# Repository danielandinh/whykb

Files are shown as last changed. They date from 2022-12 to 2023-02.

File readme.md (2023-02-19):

# Custom Keyboard Project

40% board w oled and knob

## Handwired Prototype
<sup><sub>not a bomb</sub></sup>

front
back

keyboard specs:
* GMK Pixel
* Gateron Milky Yellows L/F
* [3D Printed Plate](cad/plate_whole.stl)
* Durock plate mount stabs
* OLED and Knob

## PCB for sea-picro board

front
back

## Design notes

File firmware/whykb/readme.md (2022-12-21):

# handwired/whykb

front

*Handwired keyboard kinda like a 40% but with arrow cluster, supports OLED Display and Rotary Encoder*

* Keyboard Maintainer: [Daniel Dinh](https://github.com/danielandinh)
* Hardware Supported: *MUC: [rp2040](https://joshajohnson.com/sea-picro/), OLED: SSD1306*

Make example for this keyboard (after setting up your build environment):

    make handwired/whykb:default

Flashing example for this keyboard:

    make handwired/whykb:default:flash

See the [build environment setup](https://docs.qmk.fm/#/getting_started_build_tools) and the [make instructions](https://docs.qmk.fm/#/getting_started_make_guide) for more information. Brand new to QMK? Start with our [Complete Newbs Guide](https://docs.qmk.fm/#/newbs).

## Bootloader

Enter the bootloader in 3 ways:

* **Bootmagic reset**: Hold down the key at (0,0) in the matrix (usually the top left key or Escape) and plug in the keyboard
* **Physical reset button**: Briefly press the button on the back of the PCB - some may have pads you must short instead
* **Keycode in layout**: Press the key mapped to `QK_BOOT` if it is available

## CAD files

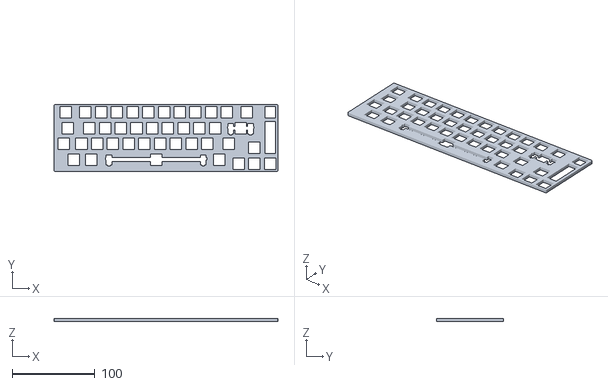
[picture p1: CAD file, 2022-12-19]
cad/plate_whole.stl
271.5 x 81.0 x 3.60

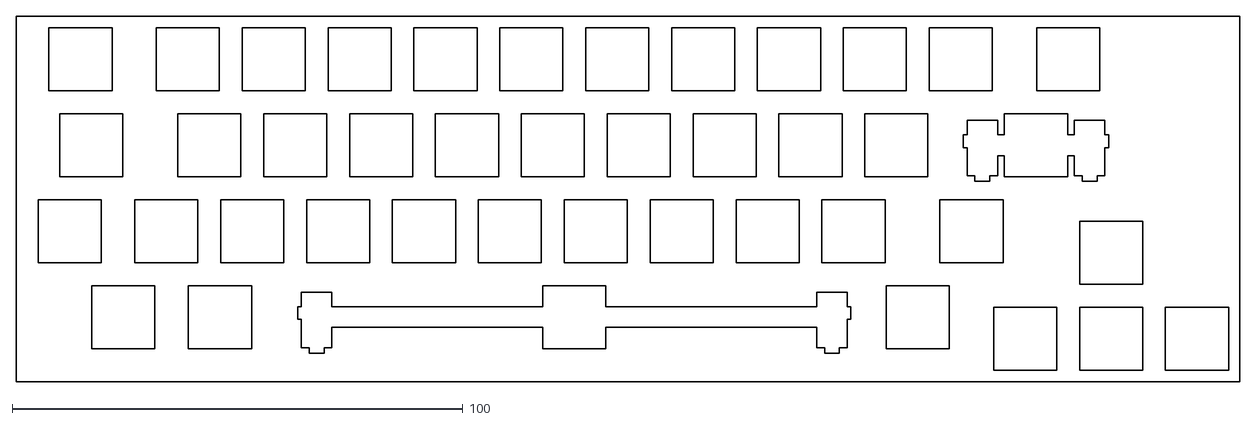
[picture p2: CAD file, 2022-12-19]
cad/whykb_plate.dxf
271.5 x 81.0

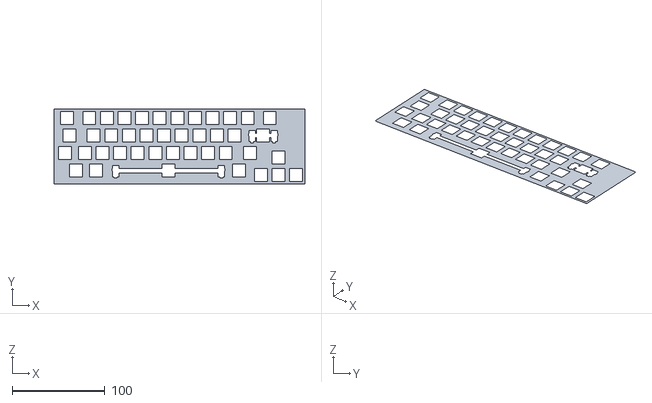
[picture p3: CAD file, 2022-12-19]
cad/plate_cad.STL
271.4 x 80.9 x 0

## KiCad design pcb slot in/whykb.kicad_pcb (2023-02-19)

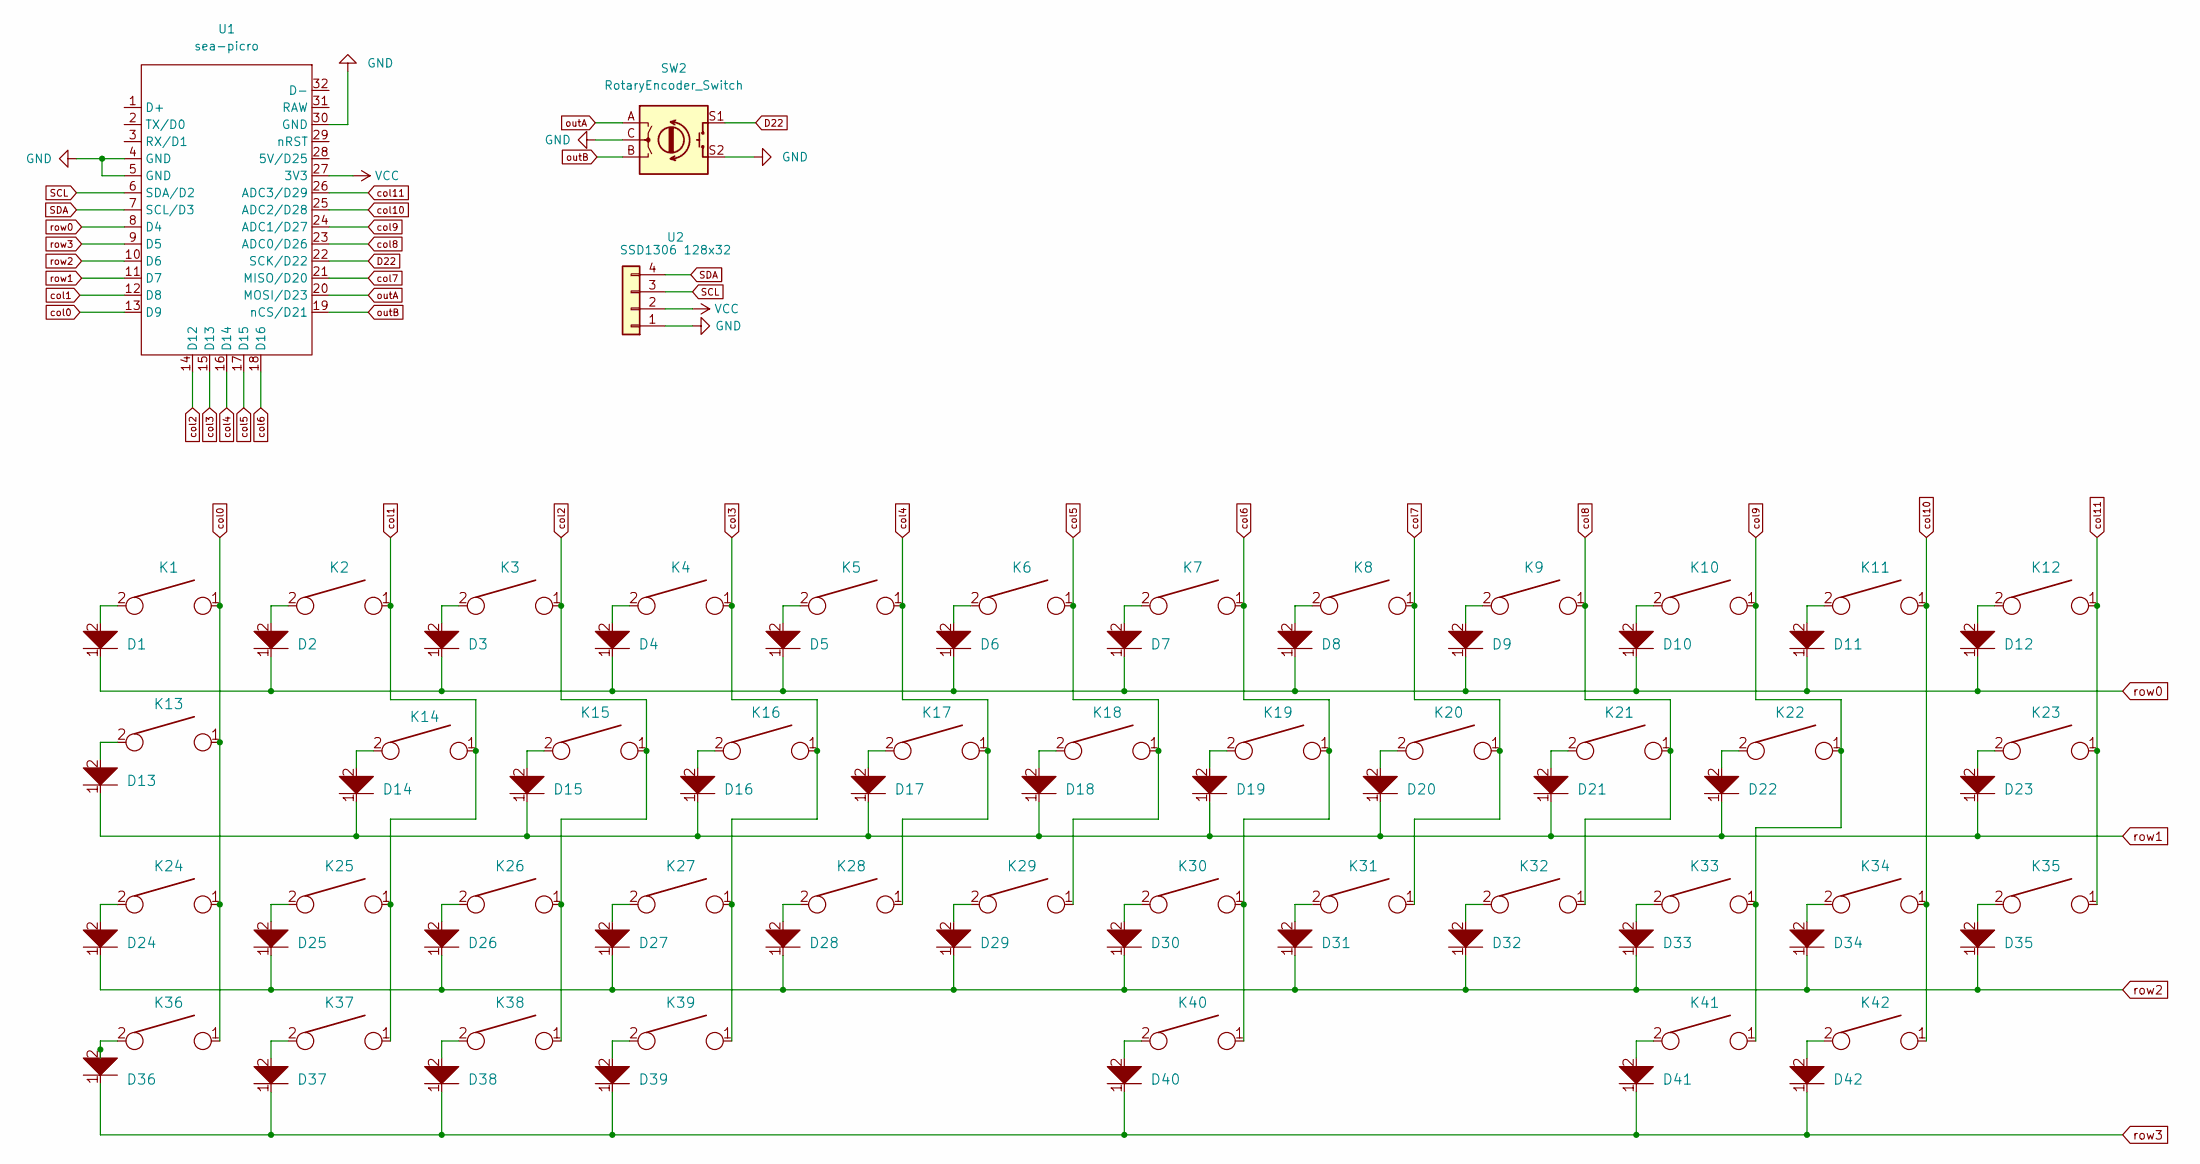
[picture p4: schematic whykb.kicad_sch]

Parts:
D1, D2, D3, D4, D5, D6, D7, D8, D9, D10, D11, D12, D13, D14, D15, D16, D17, D18, D19, D20, D21, D22, D23, D24, D25, D26, D27, D28, D29, D30, D31, D32, D33, D34, D35, D36, D37, D38, D39, D40, D41, D42: D; D_SOD123
K1, K12: KEYSW; MXOnly-1.5U-NoLED
K2, K3, K4, K5, K6, K7, K8, K9, K10, K11, K14, K15, K16, K17, K18, K19, K20, K21, K22, K24, K26, K27, K28, K29, K30, K31, K32, K33, K34, K36, K37, K38, K39, K42: KEYSW; MXOnly-1U-NoLED
K13: KEYSW; MXOnly-2.25U-NoLED
K23, K25: KEYSW; MXOnly-1.75U-NoLED
K35, K41: KEYSW; MXOnly-1.25U-NoLED
K40: KEYSW; MXOnly-7U-NoLED
SW2: RotaryEncoder_Switch; RotaryEncoder_Alps_EC11E-Switch_Vertical_H20mm
U1: sea-picro
U2: SSD1306 128x32; SSD1306-0.91-OLED-4pin-128x32

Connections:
D22: SW2.S1, U1.22 (SCK/D22)
GND: SW2.C, SW2.S2, U1.4 (GND), U1.5 (GND), U1.30 (GND), U2.1
unnamed: D1.2, K1.2
unnamed: D2.2, K2.2
unnamed: D3.2, K3.2
unnamed: D4.2, K4.2
unnamed: D5.2, K5.2
unnamed: D6.2, K6.2
unnamed: D7.2, K7.2
unnamed: D8.2, K8.2
unnamed: D9.2, K9.2
unnamed: D10.2, K10.2
unnamed: D11.2, K11.2
unnamed: D12.2, K12.2
unnamed: D13.2, K13.2
unnamed: D14.2, K14.2
unnamed: D15.2, K15.2
unnamed: D16.2, K16.2
unnamed: D17.2, K17.2
unnamed: D18.2, K18.2
unnamed: D19.2, K19.2
unnamed: D20.2, K20.2
unnamed: D21.2, K21.2
unnamed: D22.2, K22.2
unnamed: D23.2, K23.2
unnamed: D24.2, K24.2
unnamed: D25.2, K25.2
unnamed: D26.2, K26.2
unnamed: D27.2, K27.2
unnamed: D28.2, K28.2
unnamed: D29.2, K29.2
unnamed: D30.2, K30.2
unnamed: D31.2, K31.2
unnamed: D32.2, K32.2
unnamed: D33.2, K33.2
unnamed: D34.2, K34.2
unnamed: D35.2, K35.2
unnamed: D36.2, K36.2
unnamed: D37.2, K37.2
unnamed: D38.2, K38.2
unnamed: D39.2, K39.2
unnamed: D40.2, K40.2
unnamed: D41.2, K41.2
unnamed: D42.2, K42.2
SCL: U1.6 (SDA/D2), U2.3
SDA: U1.7 (SCL/D3), U2.4
VCC: U1.27 (3V3), U2.2
col0: K1.1, K13.1, K24.1, K36.1, U1.13 (D9)
col1: K2.1, K14.1, K25.1, K37.1, U1.12 (D8)
col2: K3.1, K15.1, K26.1, K38.1, U1.14 (D12)
col3: K4.1, K16.1, K27.1, K39.1, U1.15 (D13)
col4: K5.1, K17.1, K28.1, U1.16 (D14)
col5: K6.1, K18.1, K29.1, U1.17 (D15)
col6: K7.1, K19.1, K30.1, K40.1, U1.18 (D16)
col7: K8.1, K20.1, K31.1, U1.21 (MISO/D20)
col8: K9.1, K21.1, K32.1, U1.23 (ADC0/D26)
col9: K10.1, K22.1, K33.1, K41.1, U1.24 (ADC1/D27)
col10: K11.1, K34.1, K42.1, U1.25 (ADC2/D28)
col11: K12.1, K23.1, K35.1, U1.26 (ADC3/D29)
outA: SW2.A, U1.20 (MOSI/D23)
outB: SW2.B, U1.19 (nCS/D21)
row0: D1.1, D2.1, D3.1, D4.1, D5.1, D6.1, D7.1, D8.1, D9.1, D10.1, D11.1, D12.1, U1.8 (D4)
row1: D13.1, D14.1, D15.1, D16.1, D17.1, D18.1, D19.1, D20.1, D21.1, D22.1, D23.1, U1.11 (D7)
row2: D24.1, D25.1, D26.1, D27.1, D28.1, D29.1, D30.1, D31.1, D32.1, D33.1, D34.1, D35.1, U1.10 (D6)
row3: D36.1, D37.1, D38.1, D39.1, D40.1, D41.1, D42.1, U1.9 (D5)

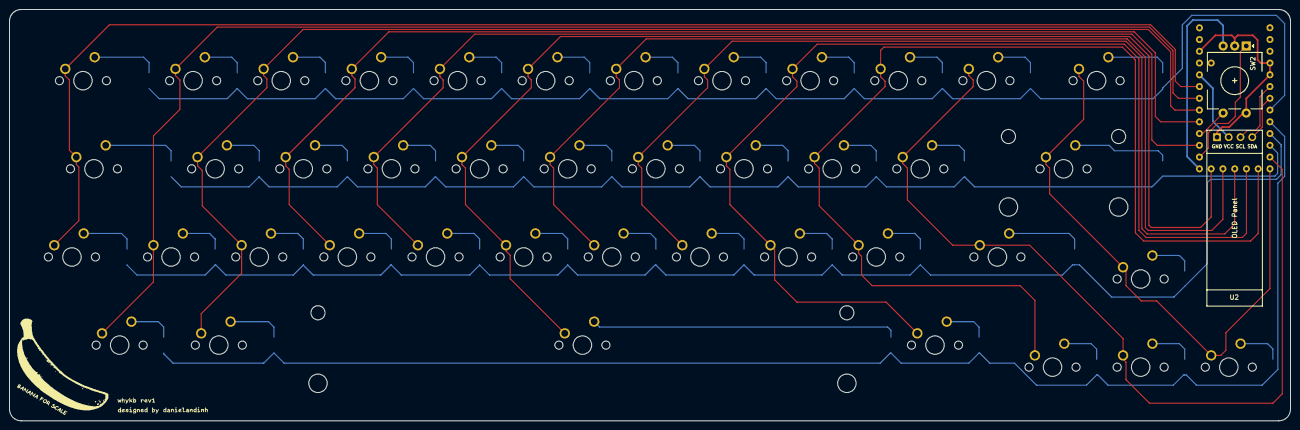
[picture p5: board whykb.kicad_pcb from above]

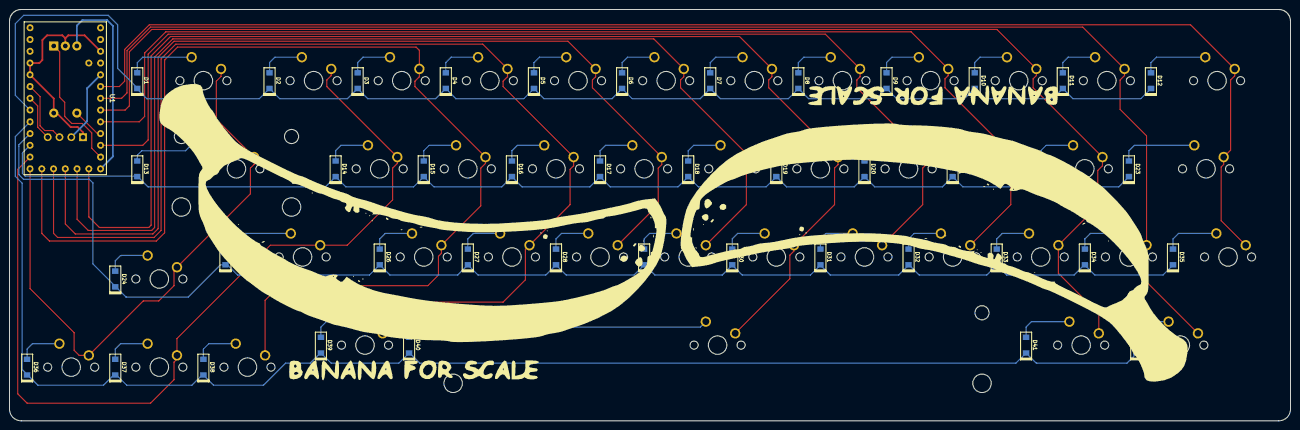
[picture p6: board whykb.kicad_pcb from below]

Board: 2 copper layers, 276.9 x 88.9 mm, 87 parts (43 on the bottom side), 65 nets.

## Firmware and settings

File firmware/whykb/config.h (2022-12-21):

// Copyright 2022 Daniel D (@danielandinh)
// SPDX-License-Identifier: GPL-2.0-or-later

#pragma once

// Rotary Encoder settings
#define ENCODERS_PAD_A { GP23 }
#define ENCODERS_PAD_B { GP21 }
#define ENCODER_RESOLUTION 4

// OLED
#ifdef OLED_ENABLE
#define OLED_DISPLAY_128X32
#define I2C1_SDA_PIN GP2
#define I2C1_SCL_PIN GP3
#define I2C_DRIVER I2CD2
#define OLED_BRIGHTNESS 128
#endif

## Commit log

2022-12-19 initial layout design
    added modelling/cad files for keyboard plate
    [plate_cad.STL, plate_whole.stl, whykb_plate.dxf]
2022-12-19 sorted things, added firmware
    firmware supports default qwerty layout only
    [plate_cad.STL, plate_whole.stl, whykb_plate.dxf]
2022-12-20 firmware update
    added support for rotary encoder
    added fn and num layers
2022-12-20 oled not working yet
    [config.h]
2022-12-20 changing i2c driver
    changed in config and mcuconf
2023-01-27 pcb files
    - created symbol for elite c board
    - finish schematic
    - cvpcb done
    [whykb.kicad_pcb, whykb.kicad_sch]
2023-01-28 made sea picro footprint
    [whykb.kicad_sch]
2023-02-09 start pcb layout
    [whykb.kicad_pcb, whykb.kicad_sch]
2023-02-19 routed traces
    [whykb.kicad_pcb, whykb.kicad_sch]
2023-02-19 update pcb
    cleaned up traces
    added some silkscreen
    generate gerbers
    [whykb-B_Cu.gbl, whykb-B_Mask.gbs, whykb-B_Silkscreen.gbo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]
2023-02-19 minor fixes
    - updated gerber setting 'subtract soldermask from silkscreen'
    - changed silkscreen
    [whykb-B_Cu.gbl, whykb-B_Mask.gbs, whykb-B_Silkscreen.gbo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]
2023-02-19 added 3d models to pcb
    [whykb.kicad_pcb]

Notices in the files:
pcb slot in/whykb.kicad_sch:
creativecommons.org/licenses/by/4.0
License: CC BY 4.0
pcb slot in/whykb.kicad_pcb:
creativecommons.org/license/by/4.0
